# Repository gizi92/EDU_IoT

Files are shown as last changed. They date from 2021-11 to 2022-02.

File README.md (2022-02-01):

# EDU_IoT
## UBB IoT  project - Smart Office

### Project structure
- NodeMCU:
    - Up to date version: `/mcus/nodemcu/spi_master`
    - Example code snippets: `/mcus/nodemcu/examples/`
    - To run the examples, you need to install the following libraries:
        - LittleFS by lorol: https://github.com/lorol/LITTLEFS
        - ESP8266WiFi: https://github.com/esp8266/Arduino/tree/master/libraries/ESP8266WiFi
        - ESPAsyncTCP by me-no-dev: https://github.com/me-no-dev/ESPAsyncTCP
        - ESPAsyncWebServer by me-no-dev: https://github.com/me-no-dev/ESPAsyncWebServer
        - Arduino_JSON by arduino-libraries: https://github.com/arduino-libraries/Arduino_JSON
        - PubSubClient by knolleary: https://github.com/knolleary/pubsubclient

- Arduino Uno:
    - Up to date version: `/mcus/arduino_uno/spi_slave`
    - Example code snippets: `/mcus/arduino_uno/examples/`
    - To run the examples, you need to install the following libraries:
        - LiquidCrystal I2C by Marco Schwartz: https://github.com/johnrickman/LiquidCrystal_I2C
        - Arduino-DS3231 by Korneliusz Jarzebski: https://github.com/jarzebski/Arduino-DS3231
        - SimpleDHT by Winlin: https://github.com/winlinvip/SimpleDHT
        - Adafruit_TSL2561 by Adafruit: https://github.com/adafruit/Adafruit_TSL2561
        - Arduino-IRRemote by Arduino: https://github.com/Arduino-IRremote/Arduino-IRremote
- Libraries:
    - path: /mcus/libraries
    - Usage instructions:
        - Windows: Copy all folders from `/mcus/libraries` to your local `/Documents/Arduino/libraries/` folder. Reopen your arduino IDE. You should see the libraries under the `Sketch->Include Library` menu item of the IDE.
        - Other OSes: check where the user libraries for arduino are stored and copy the content of `/mcus/libraries/` there (Imma captain obvious). Alternatively you can create zip archives from the libraries (for ex `EDU_IoT_DataPacket.zip`) and import them into
        the Arduino IDE by using the `Sketch->Include Library->Add .ZIP Library...` function.

# Tools
- If you want to use VSCode for Arduino: https://www.youtube.com/watch?v=FnEvJXpxxNM&t=300s
- PlatformIO is a cool VSCode plugin for embedded programming: https://randomnerdtutorials.com/vs-code-platformio-ide-esp32-esp8266-arduino/
- vagrant and virtualbox for mqtt server.

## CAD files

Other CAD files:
3d_models/edu_iot_smart_office_housing.skp

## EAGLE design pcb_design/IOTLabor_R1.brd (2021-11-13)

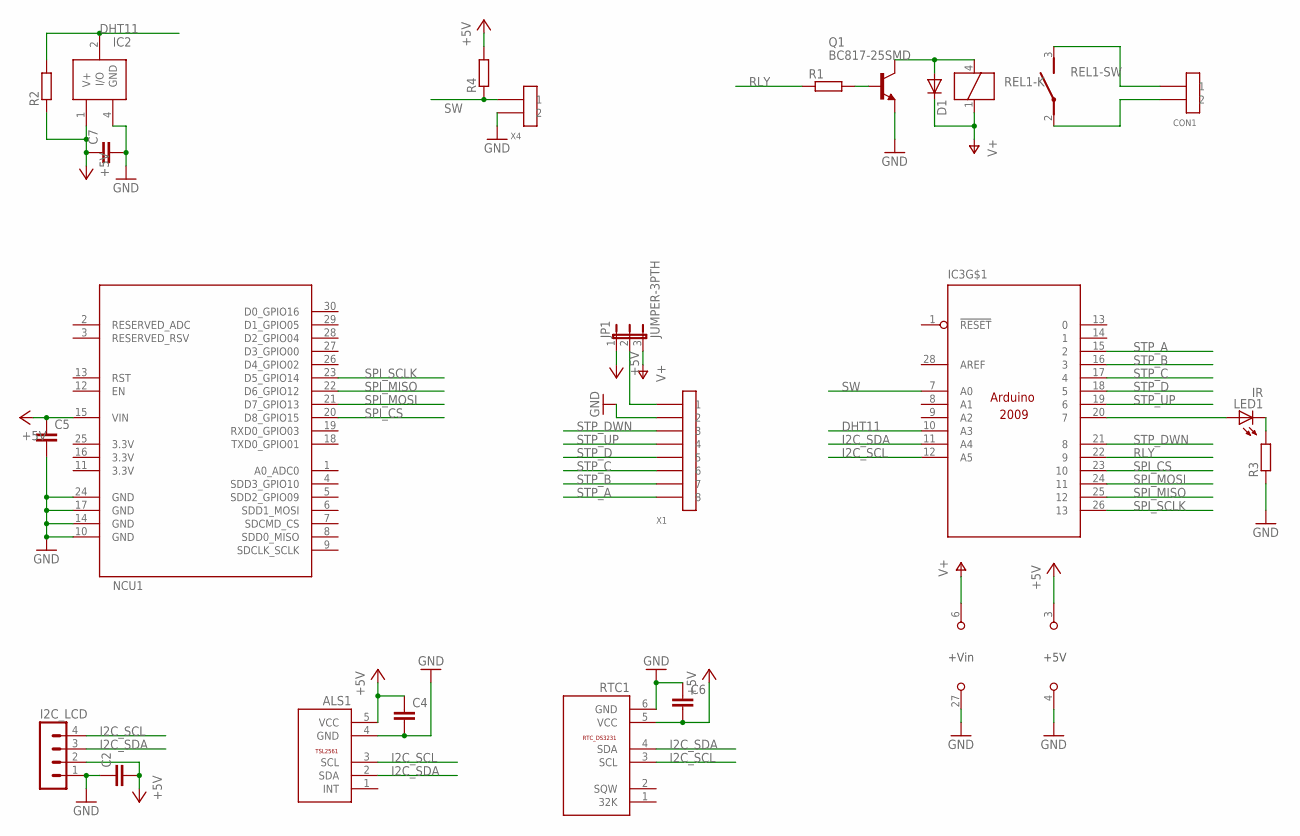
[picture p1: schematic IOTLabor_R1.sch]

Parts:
ALS1: TSL2561
C2, C4, C5, C6, C7: C-EUC0805K; C0805K
CON1: 2EDGVC-5.0-02P
D1: DIODE-MICROMELF-W; MICROMELF-W
I2C_LCD: MA04-1
IC2: DHT11V
IC3: ARDUINO2009_20; ARDUINO2009
JP1: JUMPER-3PTH; 1X03
LED1: IR; LED3MM
NCU1: NODEMCU8266
Q1: BC817-25SMD; SOT23-BEC
R1, R2, R3, R4: R-EU_R0805; R0805
REL1: 0J-SS-112
RTC1: RTC_DS3231; RTC
X1: 15EDG-8PV; 15EDGVC-3.5-08P
X4: 15EDG-2PV; 15EDGVC-3.5-02P

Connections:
3.3V: NCU1.11 (3.3V), NCU1.16 (3.3V), NCU1.25 (3.3V)
+3V3: IC3.2 (+3V3)
+5V: ALS1.5 (VCC), C2.2, C4.1, C5.1, C6.2, C7.1, I2C_LCD.2, IC2.1 (V+), IC3.3 (+5V), JP1.1, NCU1.15 (VIN), R2.1, R4.2, RTC1.5 (VCC)
DHT11: IC2.2 (I/O), IC3.10 (A3), R2.2
GND: ALS1.4 (GND), C2.1, C4.2, C5.2, C6.1, C7.2, I2C_LCD.1, IC2.4 (GND), IC3.4 (GND), IC3.5 (GND), IC3.27 (GND), NCU1.10 (GND), NCU1.14 (GND), NCU1.17 (GND), NCU1.24 (GND), Q1.E, R3.1, RTC1.6 (GND), X1.2, X4.2
I2C_SCL: ALS1.3 (SCL), I2C_LCD.4, IC3.12 (A5), RTC1.3 (SCL)
I2C_SDA: ALS1.2 (SDA), I2C_LCD.3, IC3.11 (A4), RTC1.4 (SDA)
unnamed: CON1.1, REL1.3
unnamed: CON1.2, REL1.2
unnamed: IC3.20 (7), LED1.A
unnamed: D1.A, Q1.C, REL1.4
unnamed: Q1.B, R1.2
unnamed: LED1.K (C), R3.2
unnamed: JP1.2, X1.1
RLY: IC3.22 (9), R1.1
SPI_CS: IC3.23 (10), NCU1.20 (D8_GPIO15)
SPI_MISO: IC3.25 (12), NCU1.22 (D6_GPIO12)
SPI_MOSI: IC3.24 (11), NCU1.21 (D7_GPIO13)
SPI_SCLK: IC3.26 (13), NCU1.23 (D5_GPIO14)
STP_A: IC3.15 (2), X1.8
STP_B: IC3.16 (3), X1.7
STP_C: IC3.17 (4), X1.6
STP_D: IC3.18 (5), X1.5
STP_DWN: IC3.21 (8), X1.3
STP_UP: IC3.19 (6), X1.4
SW: IC3.7 (A0), R4.1, X4.1
V+: D1.C, IC3.6 (+VIN), JP1.3, REL1.1

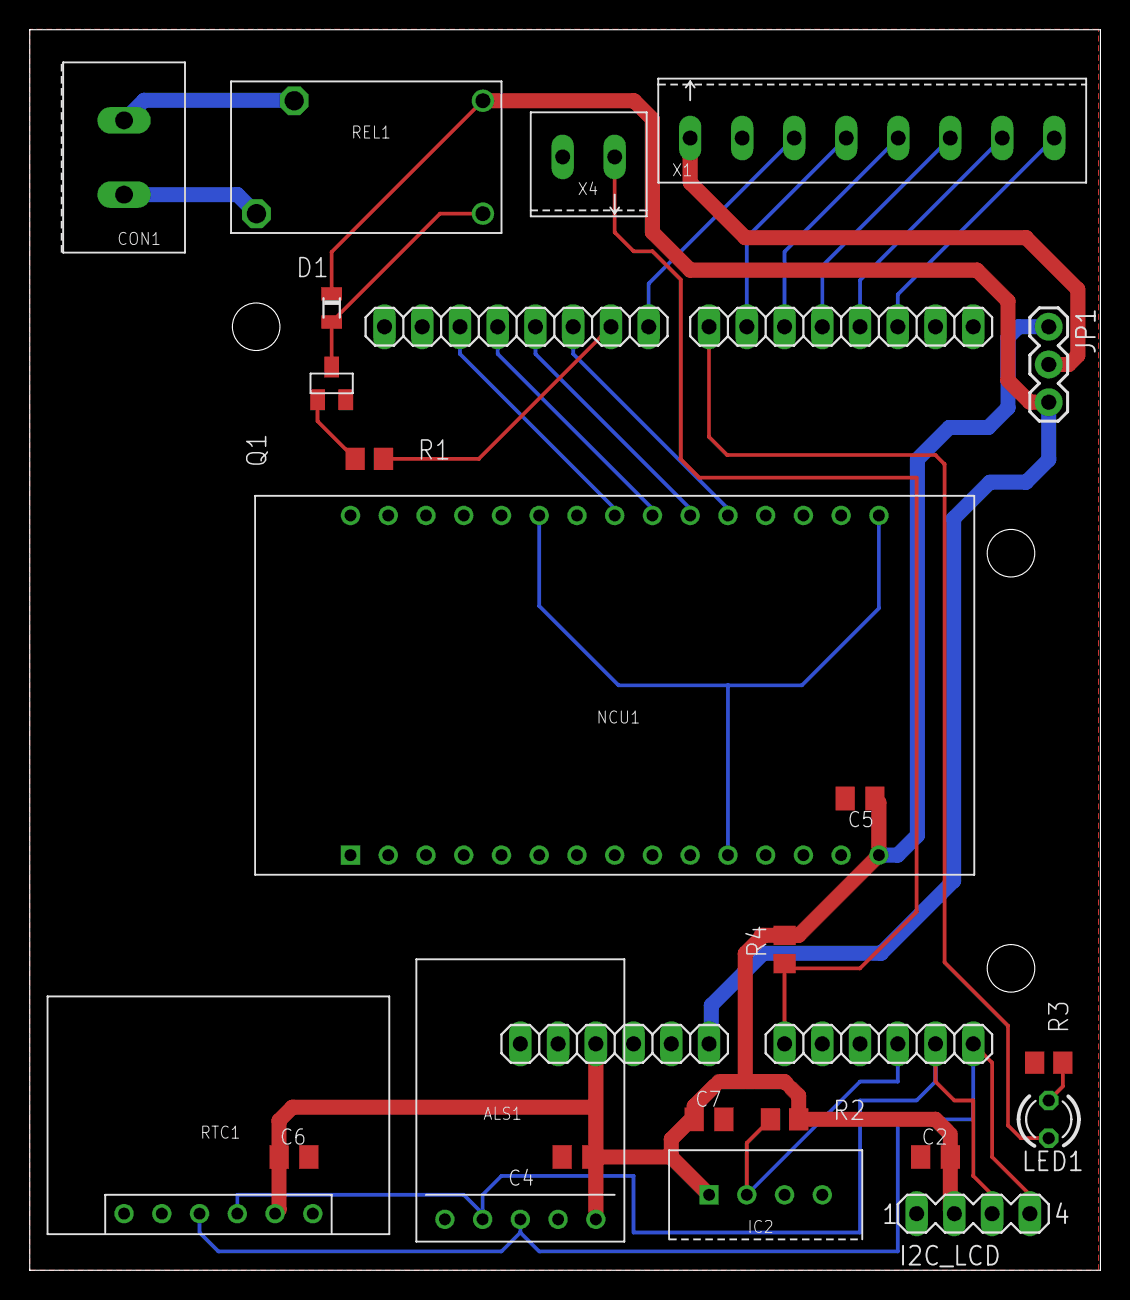
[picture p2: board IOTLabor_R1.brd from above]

Board: 2 copper layers, 72.1 x 83.5 mm, 23 parts (0 on the bottom side), 26 nets.

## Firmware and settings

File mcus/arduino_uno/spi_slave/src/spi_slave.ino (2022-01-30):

#include <SPI.h>
#include <Wire.h> //RTC
#include <DS3231.h> //RTC
#include <LiquidCrystal_I2C.h> //LCD
#include <Adafruit_Sensor.h> //TSL2561 Light sensor
#include <Adafruit_TSL2561_U.h> //TSL2561 Light sensor
#include <SimpleDHT.h> // DHT 11 humidity and temperature
#include <Stepper.h> // Stepper motor
#include <IRremote.hpp> // IR remote
#include "ac_LG.hpp" // IR remote
#include <DataPacket.h>
#include <Peripheral.h>
#include <EduIotErrorHandler.h>

//For LG Air Conditioning IR remote
#define IR_SEND_PIN               7
#define SIZE_OF_RECEIVE_BUFFER   10
char sRequestString[SIZE_OF_RECEIVE_BUFFER];
Aircondition_LG MyLG_Aircondition;
volatile bool isAirConditioningON;
//====================================

//Define Constants
//================
//Pins
// const uint8_t pin_IR_LED = 7;
const uint8_t pin_Relay = 9; // works only if 12V supplied on Arduino VIN
const uint8_t pin_ManualSwitch = 14;
const uint8_t pin_dht11 = 17;
const uint8_t pin_stepper_In1 = 8;
const uint8_t pin_stepper_In2 = 6;
const uint8_t pin_stepper_In3 = 5;
const uint8_t pin_stepper_In4 = 4;

//I2C Addresses
const uint8_t i2c_addr_LCD = 0x27;
const uint8_t i2c_addr_TSL2561 = 0x39;
const uint8_t i2c_addr_RTC = 0x68; //TODO find out how to use it
//Settings

// Stepper motor
// Number of steps per internal motor revolution
const float stepper_steps_per_rev = 32;
// Amount of Gear Reduction
const float stepper_gear_red = 64;
// Number of steps per geared output rotation
const float stepper_steps_per_out_rev = stepper_steps_per_rev * stepper_gear_red;
// Speed - TODO - get this param remotely
const float stepper_speed = 100;

volatile bool stepper_spi_cmd_cw;
volatile bool stepper_spi_cmd_ccw;

//================
// Define Variables

//OUTPUTS
DigitalOutput relaySwitch(pin_Relay);
LiquidCrystal_I2C lcd(i2c_addr_LCD,20,4);
Stepper stepperMotor(stepper_steps_per_rev, pin_stepper_In1, pin_stepper_In2, pin_stepper_In3, pin_stepper_In4);

//INPUTS
DS3231 rtc; // I2C ADDRESS 0x68
Adafruit_TSL2561_Unified tsl = Adafruit_TSL2561_Unified(i2c_addr_TSL2561, 10);
SimpleDHT11 dht11(pin_dht11);
DigitalInput ManualSwitch(pin_ManualSwitch);
GenericSensor<int32_t> LightSensor(0);
GenericSensor<int16_t> HumiditySensor(0);
GenericSensor<int16_t> TemperatureSensor(0);

// Helper Variables
// Peripherals
volatile SRealTimeClockDateTime *rtcPtr;
volatile RTCDateTime rtcDateTime;
volatile sensors_event_t tsl_event;
volatile byte temperature;
volatile byte humidity;
volatile int stepper_stepsRequired;
volatile int manualSwitchOldState;
// SPI
volatile byte spi_index_received;
volatile byte spi_index_sent;
volatile bool spi_receive;
volatile bool spi_send;
volatile bool spi_end_transmission;
SPISettings spi_settings(100000, MSBFIRST, SPI_MODE0);
// DATA PACKETS
volatile SPacketAllSensors clientDataPacket;
volatile uint8_t* dataPacketIndex;
volatile EMasterPacketTypes masterPacketType;

//Error Handling
EDU_IOT_ErrorHandler errorHandler;

bool init_peripherals(void)
{
  Serial.begin(115200);
  /*=========================================
    Initialize Real Time Clock
    ========================================= */
  if(!rtc.begin())
  {
    errorHandler.HandleCode(IOT_ERR_RTC_CONN);
  }
  // rtc.setDateTime(__DATE__, __TIME__); //Uncomment, if you want to reset the time and date.

  /*=========================================
    Initialize  Light Sensor: Configure the gain and integration time for the TSL2561
    ========================================= */
  //use tsl.begin() to default to Wire,
  //tsl.begin(&Wire2) directs api to use Wire2, etc.
  if(!tsl.begin())
  {
    /* There was a problem detecting the TSL2561 ... check your connections */
    errorHandler.HandleCode(IOT_ERR_TSL2561_CONN);
    return false;
  }
  /* You can also manually set the gain or enable auto-gain support */
  // tsl.setGain(TSL2561_GAIN_1X);      /* No gain ... use in bright light to avoid sensor saturation */
  // tsl.setGain(TSL2561_GAIN_16X);     /* 16x gain ... use in low light to boost sensitivity */
  tsl.enableAutoRange(true);            /* Auto-gain ... switches automatically between 1x and 16x */

  /* Changing the integration time gives you better sensor resolution (402ms = 16-bit data) */
  // tsl.setIntegrationTime(TSL2561_INTEGRATIONTIME_13MS);      /* fast but low resolution */
  tsl.setIntegrationTime(TSL2561_INTEGRATIONTIME_101MS);  /* medium resolution and speed   */
  // tsl.setIntegrationTime(TSL2561_INTEGRATIONTIME_402MS);  /* 16-bit data but slowest conversions */

  /* Update these values depending on what you've set above! */
  // Serial.println("------------------------------------");
  // Serial.print  ("Gain:         "); Serial.println("Auto");
  // Serial.print  ("Timing:       "); Serial.println("101 ms");
  // Serial.println("------------------------------------");
  /*=========================================
    Initialize LCD
    ========================================= */
  lcd.init();
  lcd.backlight();

  // SPI Setup
  SPCR |= bit(SPE);         //bekapcsolja az SPIt
  pinMode(MISO, OUTPUT);    //MISOn valaszol
  spi_index_received = 0;
  spi_index_sent = 0;
  spi_receive = true;
  spi_send = false;
  spi_end_transmission = false;
  dataPacketIndex = (uint8_t*)&clientDataPacket;

  //CMD LightSwitch
  ManualSwitch.ReadState();
  manualSwitchOldState = ManualSwitch.GetLastReadValue();
  //CMD Stepper
  stepper_spi_cmd_cw = false;
  stepper_spi_cmd_ccw = false;

  //IR remote to LG Air  Conditioning
  Serial.println(F("START " __FILE__ " from " __DATE__ "\r\nUsing library version " VERSION_IRREMOTE));
#if defined(IR_SEND_PIN)
    IrSender.begin(IR_SEND_PIN); // Start with IR_SEND_PIN as send pin and enable feedback LED at default feedback LED pin
#else
    IrSender.begin(IR_SEND_PIN, ENABLE_LED_FEEDBACK); // Specify send pin and enable feedback LED at default feedback LED pin
#endif
  Serial.print(F("Ready to send IR signals at pin "));
  Serial.println(IR_SEND_PIN);
  Serial.println();
  MyLG_Aircondition.setType(LG_IS_WALL_TYPE);
  isAirConditioningON = false;
  return true;
}

// Print all data to the LCD
void lcd_print_all(void)
{
  lcd.clear();
  //row 1
  lcd.setCursor(0,0);
  lcd.print("Date:");
  lcd.print(rtcDateTime.year, 10);
  lcd.print("-");
  lcd.print(rtcDateTime.month, 10);
  lcd.print("-");
  lcd.print(rtcDateTime.day, 10);
  // row 2
  lcd.setCursor(0,1);
  lcd.print("Time:");
  lcd.print(rtcDateTime.hour, 10);
  lcd.print(":");
  lcd.print(rtcDateTime.minute, 10);
  lcd.print(":");
  lcd.print(rtcDateTime.second, 10);
  // row 3
  lcd.setCursor(0,2);
  lcd.print("Light: "); lcd.print(LightSensor.GetLastReadValue()); lcd.print(" lux");
  // row 4
  lcd.setCursor(0,3);
  lcd.print("DHT11: "); lcd.print(TemperatureSensor.GetLastReadValue()); lcd.print(" *C, "); lcd.print(HumiditySensor.GetLastReadValue()); lcd.print(" H");
}



void setup (void)
{
  Serial.begin(115200);
    if(!init_peripherals())
    {
      errorHandler.HandleCode(IOT_ERR_SYS_INIT_FAIL);
    }
    else
    {
      SPI.attachInterrupt();   //ha jon az SPIn  valami beugrik a fuggvenybe
    }
}


void loop ()
{
  if(stepper_spi_cmd_cw)
  {
    SPI.detachInterrupt();
    stepper_stepsRequired = stepper_steps_per_out_rev/2;
    stepperMotor.setSpeed(stepper_speed);
    stepperMotor.step(stepper_stepsRequired);
    stepper_spi_cmd_cw = false;
    SPI.attachInterrupt();
  }
  else if (stepper_spi_cmd_ccw)
  {
    SPI.detachInterrupt();
    stepper_stepsRequired = - stepper_steps_per_out_rev/2;
    stepperMotor.setSpeed(stepper_speed);
    stepperMotor.step(stepper_stepsRequired);
    stepper_spi_cmd_ccw = false;
    SPI.attachInterrupt();
  }

  /*=========================================
    Get RTC data
    ========================================= */
  rtcDateTime = rtc.getDateTime();

  /*=========================================
    Get Light Sensor data (light is measured in lux)
    ========================================= */
  tsl.getEvent(&tsl_event);
  if (tsl_event.light)
  {
    LightSensor.SetValue((int32_t)tsl_event.light);
  }
  else
  {
    /* If event.light = 0 lux the sensor is probably saturated
       and no reliable data could be generated! */
    errorHandler.HandleCode(IOT_ERR_TSL2561_OVERLOAD);
    LightSensor.SetValue(0);
  }
  /*=========================================
    Get Temperature and Humidity Data
    ========================================= */
  int err = SimpleDHTErrSuccess;
  if ((err = dht11.read(&temperature, &humidity, NULL)) != SimpleDHTErrSuccess)
  {
    errorHandler.HandleCode(IOT_ERR_DHT11_GENERAL);
    HumiditySensor.SetValue(0);
    TemperatureSensor.SetValue(0);
  }
  else
  {
    HumiditySensor.SetValue((int16_t)humidity);
    TemperatureSensor.SetValue((int16_t)temperature);
  }
  /*=========================================
    Read Manual Switch State
    ========================================= */
  ManualSwitch.ReadState();
  // If switch state changed, execute command
  if (manualSwitchOldState != ManualSwitch.GetLastReadValue())
  {
    manualSwitchOldState = ManualSwitch.GetLastReadValue();
    if(manualSwitchOldState)
      relaySwitch.TurnOFF();
    else
    {
      relaySwitch.TurnON();
    }
  }

  /*=========================================
    Print Data to LCD
    ========================================= */
  lcd_print_all();
  /*=========================================
    Handle SPI transmission end
    ========================================= */
  if (spi_end_transmission)
  {
    spi_end_transmission = false;
    spi_receive = true;
    spi_send = false;

    dataPacketIndex = (uint8_t*)&clientDataPacket;
    spi_index_sent = 0;
  }

  delay(1000);
}

// SPI interrupt routine
ISR(SPI_STC_vect)
{
  //receive and handle master request
  uint8_t receivedByte = (uint8_t)SPDR;
  if(spi_receive)
  {
    masterPacketType = (EMasterPacketTypes)receivedByte;
    //Prepare clientDataPackage for sending to master
    switch (masterPacketType)
    {
    case EMasterPacketTypes::ReadAllSensors:
      {
        Serial.println("[UNO] Received master packet ReadAllSensors");
        Serial.println();
        clientDataPacket.error = 0;
        clientDataPacket.roomLightSwitchState = relaySwitch.GetState();
        clientDataPacket.humidiySensor = HumiditySensor.GetLastReadValue();
        clientDataPacket.temperatureSensor = TemperatureSensor.GetLastReadValue();
        clientDataPacket.lightSensor = LightSensor.GetLastReadValue();
        // TODO simplify
        clientDataPacket.rtcDateTime.year = rtcDateTime.year;
        clientDataPacket.rtcDateTime.month = rtcDateTime.month;
        clientDataPacket.rtcDateTime.day = rtcDateTime.day;
        clientDataPacket.rtcDateTime.hour = rtcDateTime.hour;
        clientDataPacket.rtcDateTime.minute = rtcDateTime.minute;
        clientDataPacket.rtcDateTime.second = rtcDateTime.second;
        clientDataPacket.rtcDateTime.dayOfWeek = rtcDateTime.dayOfWeek;
        clientDataPacket.rtcDateTime.unixtime = rtcDateTime.unixtime;
        break;
      }
    case EMasterPacketTypes::TurnLightsON:
      {
        Serial.println("[UNO] Received master packet - TurnLightsON");
        Serial.println();
        relaySwitch.TurnON();
        break;
      }
    case EMasterPacketTypes::TurnLightsOFF:
      {
        Serial.println("[UNO] Received master packet - TurnLightsOFF");
        Serial.println();
        relaySwitch.TurnOFF();
        break;
      }

    case EMasterPacketTypes::TurnStepperMotorCW:
      {
        Serial.println("[UNO] Received master packet - TurnStepperMotorCW");
        stepper_spi_cmd_cw = true;
        break;
      }
    case EMasterPacketTypes::TurnStepperMotorCCW:
      {
        Serial.println("[UNO] Received master packet - TurnStepperMotorCCW");
        stepper_spi_cmd_ccw = true;
        break;
      }
    case EMasterPacketTypes::ToggleAirConditioning:
      {
        Serial.println("[UNO] Received master packet - ToggleAirConditioning");
        if(isAirConditioningON)
        {
          MyLG_Aircondition.sendIRCommand(LG_COMMAND_ON);
          isAirConditioningON = true;
        }
        {
          MyLG_Aircondition.sendIRCommand(LG_COMMAND_OFF);
          isAirConditioningON = false;
        }
        break;
      }
    default:
      {
        Serial.print("[UNO] Unknown master packet with type ");
        Serial.println();
        Serial.println((uint8_t)masterPacketType);
        clientDataPacket.error = -1;
        break;
      }
    }
    spi_receive = false;
    spi_send = true;
  }

  if(spi_send)
  {
    if(masterPacketType == EMasterPacketTypes::ReadAllSensors)
    {
      SPDR = *dataPacketIndex++;
      spi_index_sent++;
      if(spi_index_sent > sizeof(clientDataPacket))
        spi_end_transmission = true;
    }
    else
    {
      spi_end_transmission = true;
    }
  }
}

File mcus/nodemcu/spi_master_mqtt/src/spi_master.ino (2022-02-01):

// Import required libraries
#include <FS.h>
#include <LittleFS.h>
#include <ESP8266WiFi.h>
#include <ESPAsyncTCP.h>
#include <ESPAsyncWebServer.h>
#include <SPI.h>
#include <DataPacket.h>
#include <Arduino_JSON.h>
#include <PubSubClient.h>

volatile SPacketAllSensors clientDataPacket;
SPISettings spi_settings(100000, MSBFIRST, SPI_MODE0);

// Replace with your network credentials
const char* ssid = "wifi_ssid"; //Replace with your own SSID
const char* password = "passwd"; //Replace with your own password
// MQTT
const char* mqtt_server = "server_hostname";
WiFiClient espClient;
PubSubClient mqtt_client(espClient);

void mqtt_reconnect()
{
  Serial.print("Attempting MQTT connection...");
  if (mqtt_client.connect("ESP8266Client")) {
      Serial.println("connected");
      // Subscribe or resubscribe to a topic
      // You can subscribe to more topics (to control more LEDs in this example)
      //mqtt_client.subscribe("room/lamp");
    } else {
      Serial.print("failed, rc=");
      Serial.print(mqtt_client.state());
      Serial.println(" try again in 5 seconds");
      // Wait 5 seconds before retrying
      delay(5000);
    }
}
const int ledPin = 2;
String ledState;

// Create AsyncWebServer object on port 80
AsyncWebServer server(80);

// Create an Event Source on /events
AsyncEventSource events("/events");

// Timer variables
unsigned long lastTime = 0;
unsigned long timerDelay = 3000;

void init_clientDataPacket()
{
  clientDataPacket.error = 0;
  clientDataPacket.humidiySensor = 0;
  clientDataPacket.lightSensor = 0;
  clientDataPacket.roomLightSwitchState = 0;
  clientDataPacket.temperatureSensor = 0;
  clientDataPacket.rtcDateTime.year = 0;
  clientDataPacket.rtcDateTime.month = 0;
  clientDataPacket.rtcDateTime.day = 0;
  clientDataPacket.rtcDateTime.dayOfWeek = 0;
  clientDataPacket.rtcDateTime.unixtime = 0;
  clientDataPacket.rtcDateTime.hour = 0;
  clientDataPacket.rtcDateTime.minute = 0;
  clientDataPacket.rtcDateTime.second = 0;
}

String rtc_datetime_to_str()
{
  String result = String();
  result.concat(clientDataPacket.rtcDateTime.year);
  result.concat("-");
  result.concat(clientDataPacket.rtcDateTime.month);
  result.concat("-");
  result.concat(clientDataPacket.rtcDateTime.day);
  result.concat("           ");
  result.concat(clientDataPacket.rtcDateTime.hour);
  result.concat(":");
  result.concat(clientDataPacket.rtcDateTime.minute);
  result.concat(":");
  result.concat(clientDataPacket.rtcDateTime.second);
  //result.concat("1Z");
  return result;
}

void send_spi_cmd(const EMasterPacketTypes cmd)
{
  if(cmd == EMasterPacketTypes::None)
  {
    Serial.println("[NODE] Invalid SPI command!");
    return;
  }

  SPI.beginTransaction(spi_settings);

  if(cmd == EMasterPacketTypes::ReadAllSensors)
  {
    //init_clientDataPacket();
    SPI.transfer((uint8_t)cmd);
    delay(1);
    uint8_t* dataPacketIndex = (uint8_t*)&clientDataPacket;
    for( int i=0; i<sizeof(clientDataPacket);  i++)
    {
      *dataPacketIndex = SPI.transfer('.');
      dataPacketIndex++;
      delay(1);
    }
    //DEBUG
    // Serial.println("[NODE] packet received:");
    // Serial.println(clientDataPacket.temperatureSensor);
    // Serial.println(clientDataPacket.humidiySensor);
    // Serial.println(clientDataPacket.lightSensor);
    // Serial.println("[NODE] packet end...");
  }
  else
  {
    SPI.transfer((uint8_t)cmd);
    delay(1);
  }
  SPI.endTransaction();
  return;
}

// Replaces placeholder with LED state value
void spi_cmd_TurnLightsON(){
  Serial.println("[NODE] send SPI Command: Turn Lights ON");
  send_spi_cmd(EMasterPacketTypes::TurnLightsON);
}

void spi_cmd_TurnLightsOFF(){
  Serial.println("[NODE] send SPI Command: Turn Lights OFF");
  send_spi_cmd(EMasterPacketTypes::TurnLightsOFF);
}

void spi_cmd_TurnStepperMotorCW()
{
  Serial.println("[NODE] send SPI Command: Turn Stepper Motor CW");
  send_spi_cmd(EMasterPacketTypes::TurnStepperMotorCW);
}

void spi_cmd_TurnStepperMotorCCW()
{
  Serial.println("[NODE] send SPI Command: Turn Stepper Motor CCW");
  send_spi_cmd(EMasterPacketTypes::TurnStepperMotorCCW);
}

void spi_cmd_ToggleAirConditioning()
{
  Serial.println("[NODE] send SPI Command: Toggle Airconditioning");
  send_spi_cmd(EMasterPacketTypes::ToggleAirConditioning);
}

String spi_cmd_ReadAllSensors()
{
  Serial.println("[NODE] update sensor data on webpage");
  if(clientDataPacket.error)
  {
    return "";
  }
  // Json Variable to hold data sent from the Arduino
  JSONVar packet_from_client;
  packet_from_client["temperature"] = String(clientDataPacket.temperatureSensor);
  packet_from_client["humidity"] = String(clientDataPacket.humidiySensor);
  packet_from_client["luminosity"] = String(clientDataPacket.lightSensor);
  packet_from_client["manualswitch"] = (clientDataPacket.roomLightSwitchState == 1);
  packet_from_client["rtc_datetime"] = rtc_datetime_to_str();
  String jsonString = JSON.stringify(packet_from_client);
  return jsonString;
}

void notFound(AsyncWebServerRequest *request) {
    request->send(404, "text/plain", "Not found");
}
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

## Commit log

2021-10-22 Lacika current status, TODO swap to SPI
    [i2cmaster.ino, i2cslave.ino]
2021-10-22 led controll and light sensor value read
2021-10-24 organizing mcus folder, add SPI debug inos, halfway there
2021-10-24 completed with LED
2021-10-24 refactor master and slave for SPI, added LED test
2021-11-13 Lab 2 - Version 1 - by Marianna
    [IOTLabor_R1.brd, IOTLabor_R1.sch]
2022-01-06 housing design for the smart office project
    [edu_iot_smart_office_housing.skp]
2022-01-24 add all datapackets without stepper
2022-01-30 webpage done, spi done, TODO IR led
2022-02-01 reorganizing workspace
    [IOTLabor_R1.brd, IOTLabor_R1.sch]
